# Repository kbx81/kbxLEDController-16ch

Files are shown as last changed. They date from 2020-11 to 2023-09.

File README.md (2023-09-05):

# kbx's 16-channel ESP32 Powered LED Strip Controller

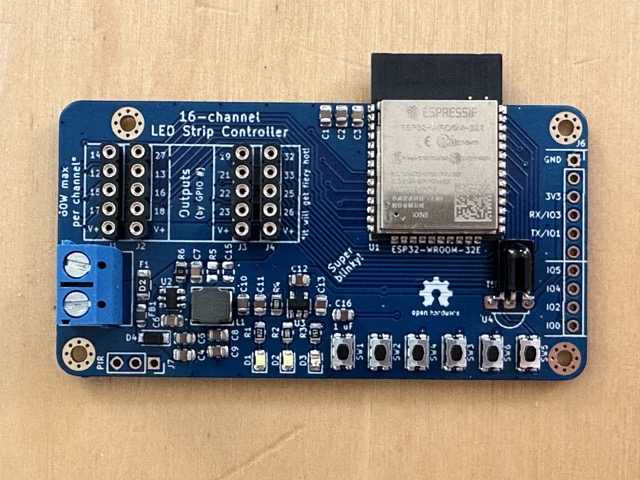
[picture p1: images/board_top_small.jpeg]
kbxLEDController-16ch PCB


## What?

Just another LED strip/tape controller...because the world needs more blinky! 💡

Note that this board is for linear/"analog" LED tape, not pixels/addressable LED tape. I recommend using a
[Quin LED](https://quinled.info) board if you need to power & drive pixels/addressable LED tape.

For more images, see the [gallery](GALLERY.md).

## Why?

I've been using more and more LED tape around my home. I wanted a replacement for/alternative to using multiple
[Magic Home](https://www.aliexpress.us/item/3256803342079819.html) LED controllers to operate multiple sections of LED
tape within a small area. Of course, having multiple controllers works, but, in my opinion, it's kind of silly and just
piles more unnecessary Wi-Fi devices onto my network. Soooooo why not make a single controller that can control a whole
bunch of strips from a single ESP32? Here we are.

In addition, I wanted something ESP32-based to minimize flicker; soft-PWM used on the ESP8266 drives me crazy in this
sense. A benefit of the ESP32 over the ESP8266 is that the ESP32 has _dedicated hardware_ for generating PWM. This
means that dimming of the LEDs is extremely smooth, consistent and flicker-free -- even at extremely low intensities!
While it's still possible on the ESP8266, LED control is just not as slick and really does not look as nice.

I've optimized this board for size (I wanted it small) and, to a lesser extent, cost. This is why it has machine-pin
headers instead of screw terminals for connecting the LED strips. I also designed it almost entirely with surface-mount
components to keep its overall footprint small -- you can easily hide it in/under a cabinet or behind/under a shelf.

While addressable LED tape is easier to drive, linear/"analog" LED tape tends to be significantly less expensive. As
fun as they are and as neat as they may look, I don't really need addressable LEDs everywhere -- linear strips work
just fine and look just as nice.

## How?

I use this board with [ESPHome](https://esphome.io) (and [Home Assistant](https://www.home-assistant.io)) but it should
work fine with [Tasmota](https://tasmota.github.io/docs/) or any other app, really.

I laid these boards out for [RGBW strips/tape](https://www.amazon.com/dp/B01D1I50UW), but they can be wired up to more
or less any kind of strips, whether monochrome, RGB, RGBW, RGBWW, the variable-color-temperature type...whatever.

They will work with a range of voltages, from 5 volts up to 24 volts.

Please see the BoM [here](kbxLEDController-16ch_bom.csv) or [here](https://octopart.com/bom-tool/OrMoA1no) for a list
of parts needed to build one. I had the PCBs fabricated by [Elecrow](https://www.elecrow.com) but nearly any PCB
fabricator should be able to manufacture these without any issues.

If you have PCBs fabricated, I _highly_ recommend having them made with 2 oz copper -- it costs a little more but
_significantly_ improves heat dissipation and allows for more current.

The schematic and PCB were drawn in [KiCad](https://www.kicad.org).

See the [ESPHome](ESPHome/) directory for a "demo" configuration you can use with [ESPHome](https://esphome.io) to test
the device after construction.

With the transistors in the BoM, _theoretically_ it should be good for up to about 60 watts per channel -- but watch
for excessive heat! Also...do not expect to be able to run all 16 channels at the full 60 watts. You're asking for
smoke and flames if you do so. Still, the layout should be pretty accommodating for high currents, especially if the
boards are fabricated with 2 oz copper (as they should be because current and heat).

## Legal stuff and License

The circuit schematics and PCB found here are licensed under the
[Creative Commons Attribution-ShareAlike 4.0 International License](http://creativecommons.org/licenses/by-sa/4.0/).



_Happy building!_

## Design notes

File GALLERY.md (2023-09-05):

# kbx's 16-channel ESP32 Powered LED Strip Controller Image Gallery

kbxLEDController-16ch PCB

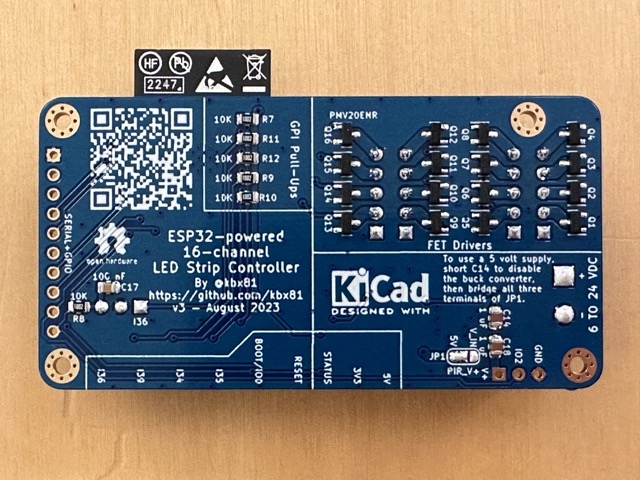
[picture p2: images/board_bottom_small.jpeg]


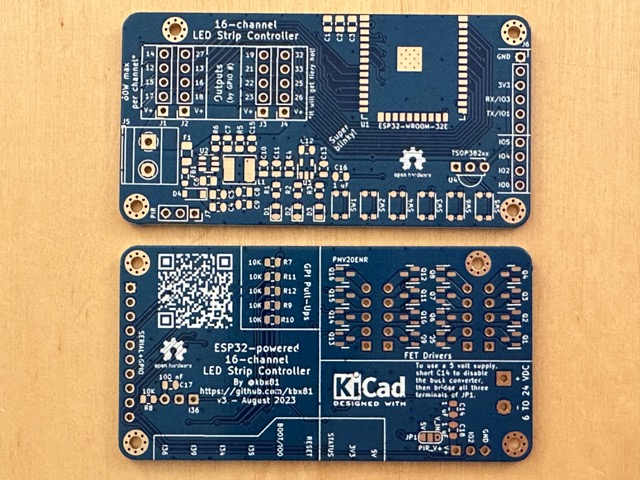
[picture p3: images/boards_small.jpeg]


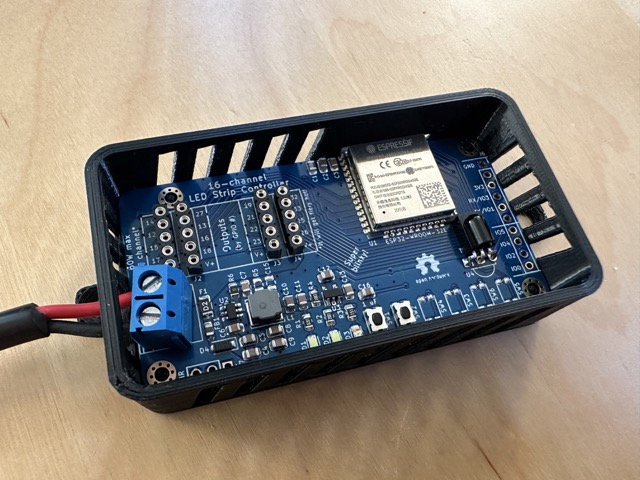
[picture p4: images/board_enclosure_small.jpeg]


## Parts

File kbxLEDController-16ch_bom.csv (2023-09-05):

Component | Quantity Per PCB | References | Value | MPN1 | Footprint | Population
1 | 4 | C3 C6 C7 C17 | 100 nF | CC0805KRX7R9BB104 | C_0805_2012Metric
2 | 7 | C2 C5 C11 C12 C14 C16 C18 | 1 uF | C2012X7R1H105K125AB | C_0805_2012Metric
3 | 3 | C1 C4 C13 | 10 uF | C2012X5R1V106K085AC | C_0805_2012Metric
4 | 3 | C8 C9 C10 | 22 uF | C2012X5R1V226M125AC | C_0805_2012Metric
5 | 2 | D1 D2 | White LED | LSM0805543V | LED_0805_2012Metric
6 | 1 | D4 | MBR120 | MBR120VLSFT1G | D_SOD-123
7 | 1 | D3 | Red LED | APT2012EC | LED_0805_2012Metric
8 | 1 | F1 | 250 mA | 1206L025/24YR | Fuse_1206_3216Metric
9 | 1 | FB1 | 600R/1A | 742792031 | L_0805_2012Metric
10 | 1 | L1 | 6.8 uH | LQH5BPN6R8M38L | L_Murata_LQH5BPN_4.9x4.9mm
11 | 16 | Q1 Q2 Q3 Q4 Q5 Q6 Q7 Q8 Q9 Q10 Q11 Q12 Q13 Q14 Q15 Q16 | PMV20ENR | PMV20ENR | SOT-23
12 | 1 | R6 | 0 | RC0805FR-070RL | R_0805_2012Metric
13 | 2 | R2 R3 | 2K | RC0805FR-072KL | R_0805_2012Metric
14 | 1 | R1 | 8K2 | RC0805FR-078K2L | R_0805_2012Metric
15 | 6 | R7 R8 R9 R10 R11 R12 | 10K | RC0805FR-0710KL | R_0805_2012Metric
16 | 1 | R4 | 100K | RC0805FR-07100KL | R_0805_2012Metric
17 | 6 | SW1 SW2 SW3 SW4 SW5 SW6 | Button | KMR221GLFS | SW_Push_1P1T_NO_CK_KMR2
18 | 1 | U3 | AP2112K-3.3 | AP2112K-3.3TRG1 | SOT-23-5
19 | 1 | U2 | AP63205WU | AP63205WU-7 | TSOT-23-6
20 | 1 | U1 | ESP32-WROOM-32E | ESP32-WROOM-32E | ESP32-WROOM-32
21 | 1 | U4 | TSOP382xx | TSOP38238 | Vishay_MINICAST-3Pin

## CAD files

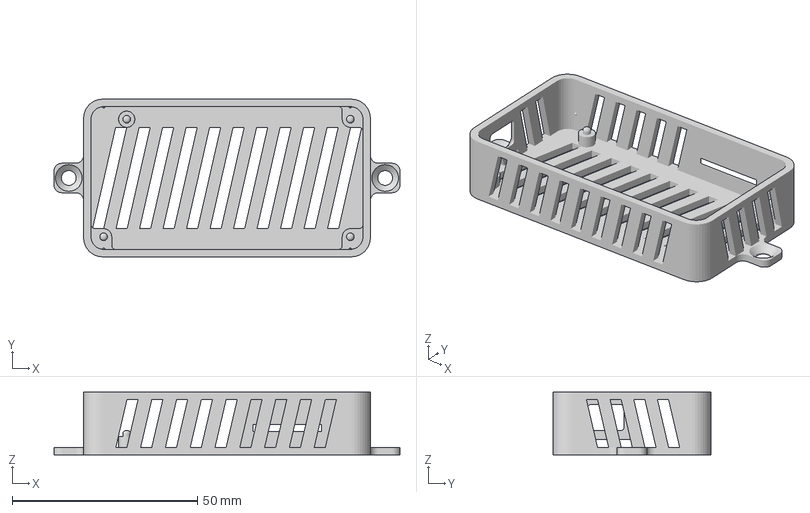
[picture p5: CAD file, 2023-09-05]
LEDController-Bottom-v3.3mf
93.5 x 42.6 x 17.0 mm

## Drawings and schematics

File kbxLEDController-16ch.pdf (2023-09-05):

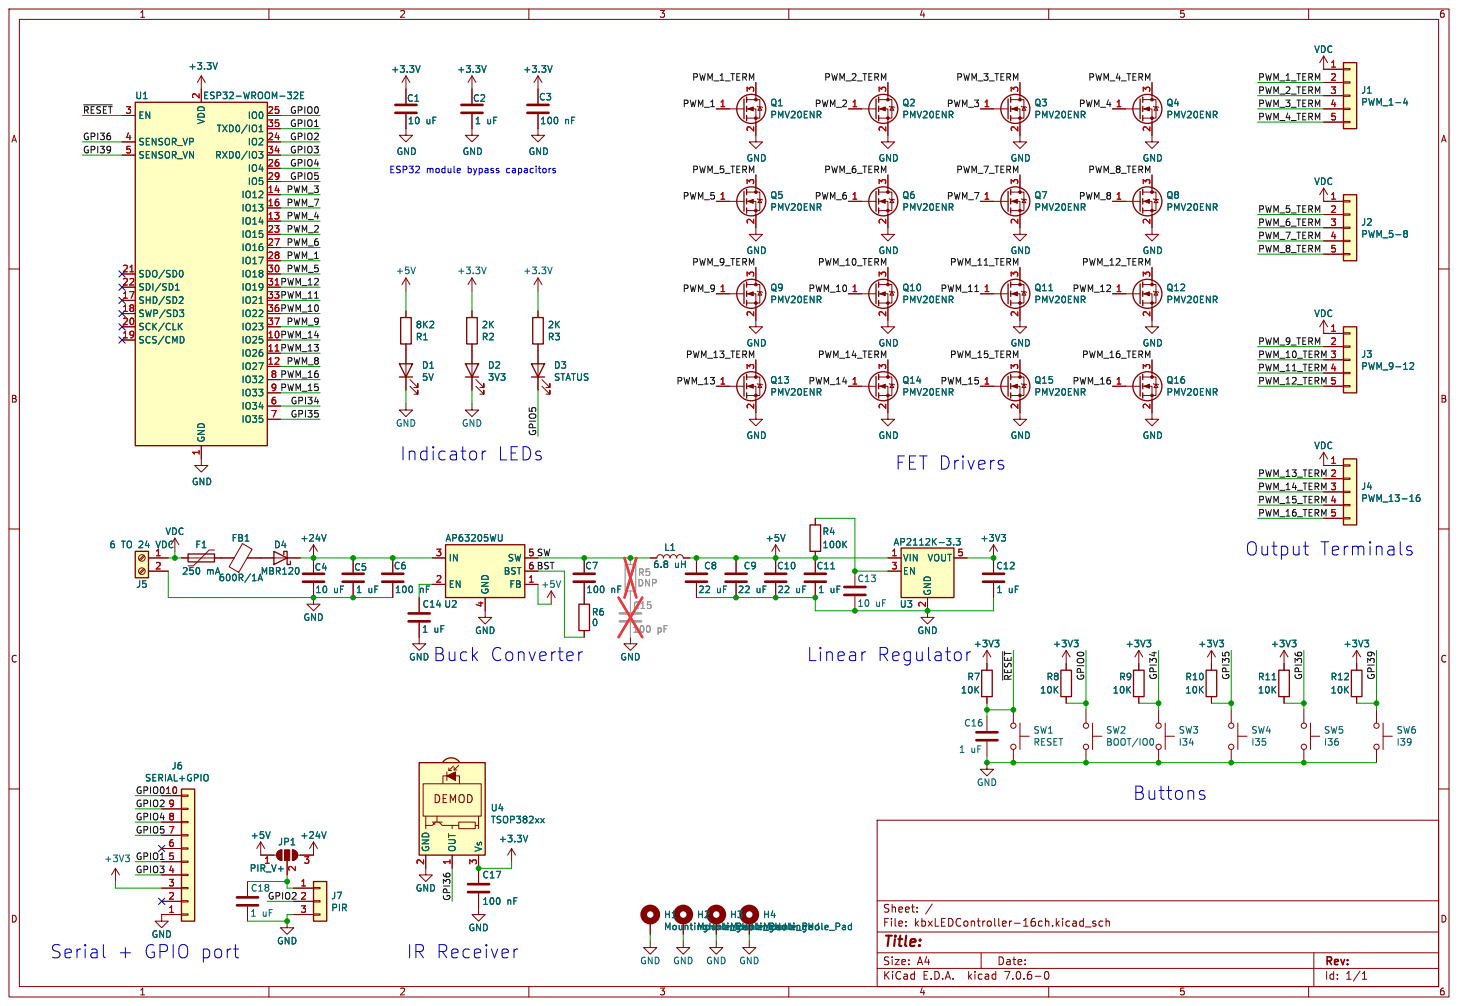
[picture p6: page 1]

2 SCK/CLK 20 SDO/SD0 21 SDI/SD1 22

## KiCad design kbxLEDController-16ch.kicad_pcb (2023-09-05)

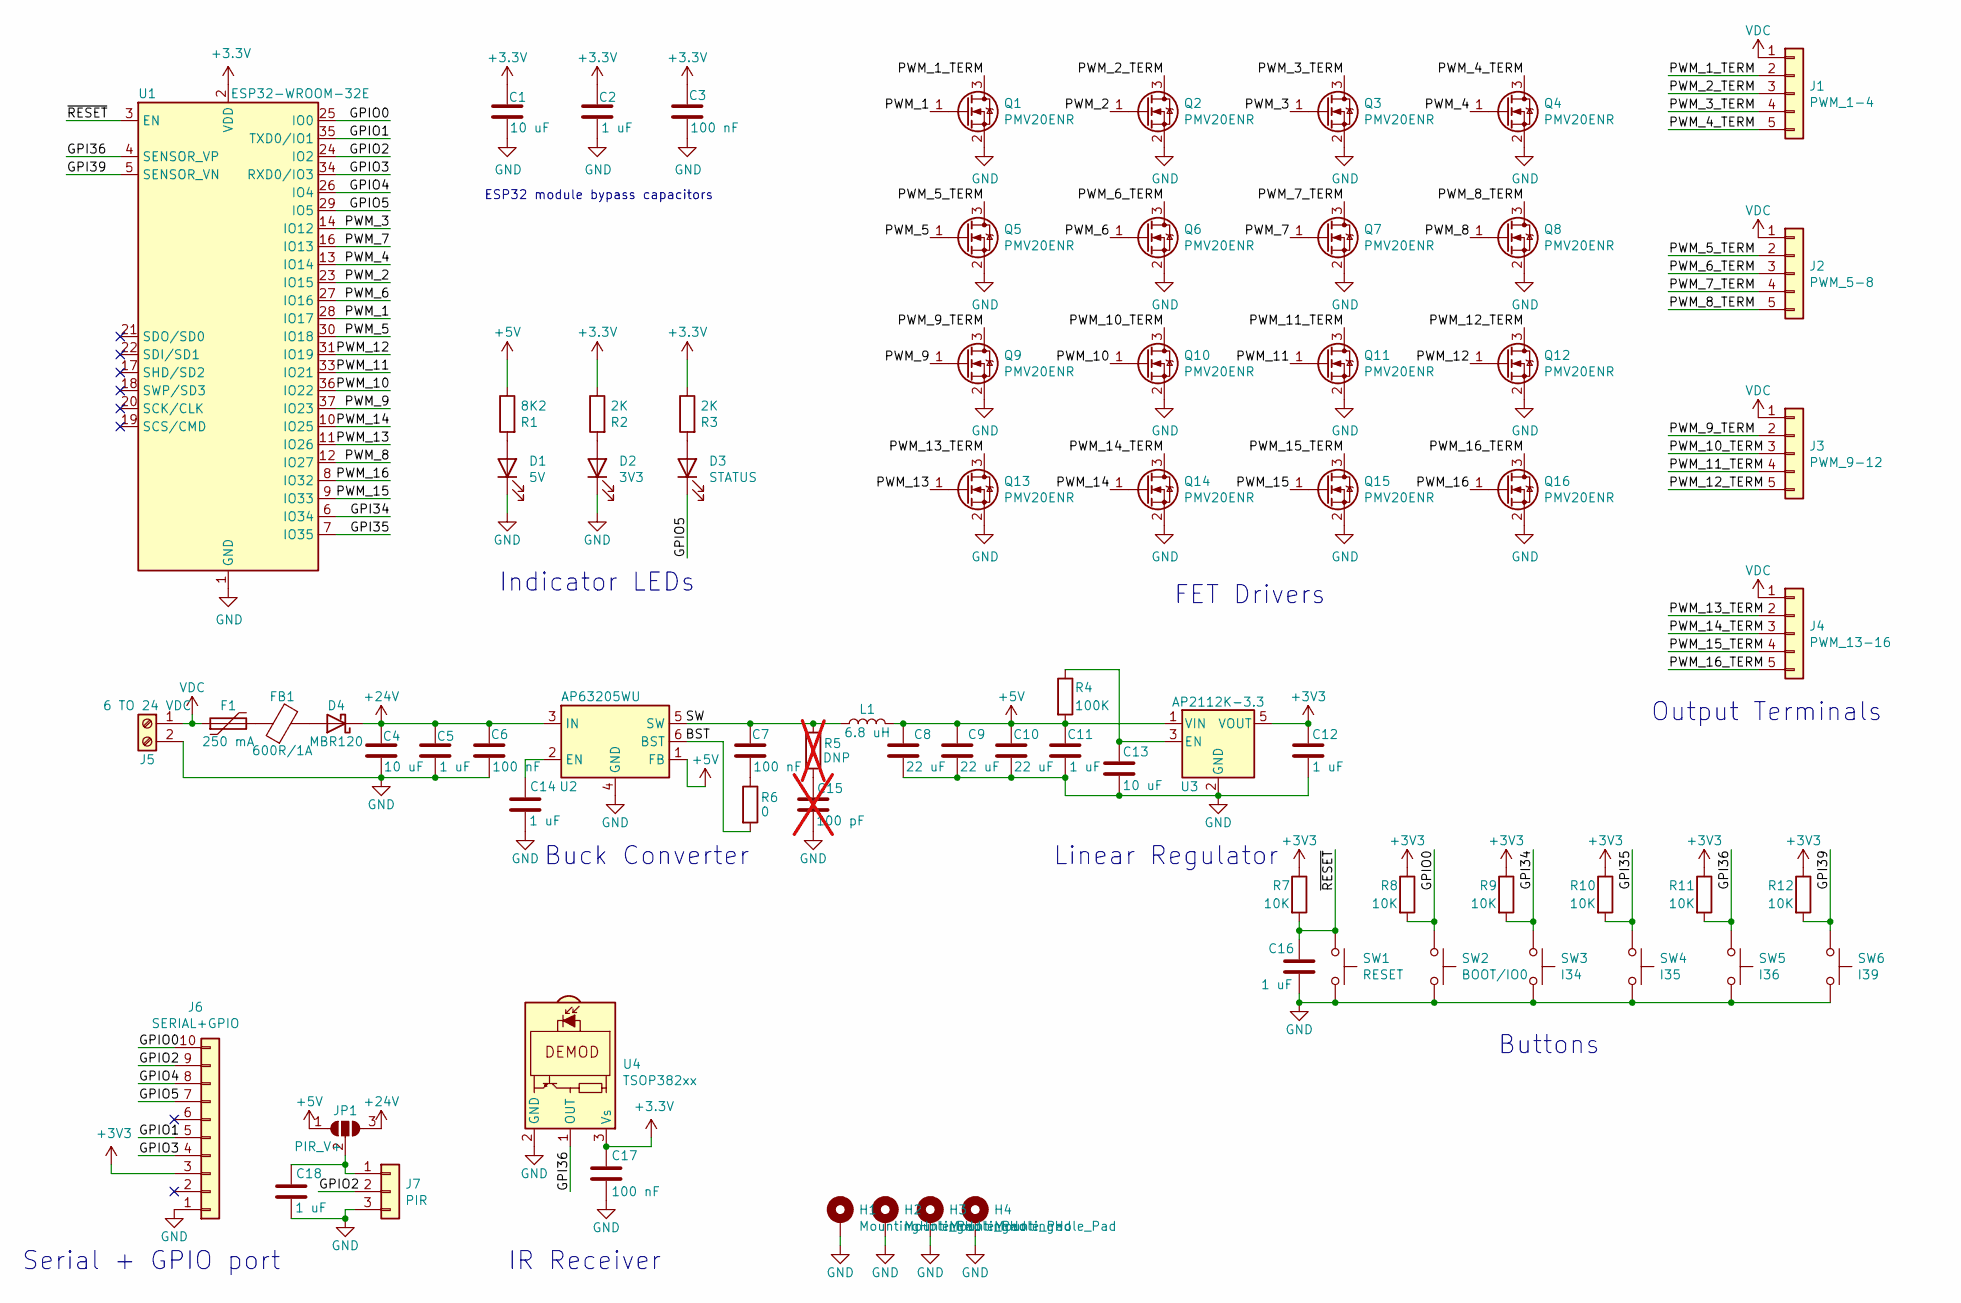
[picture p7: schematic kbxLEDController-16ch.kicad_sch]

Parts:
C1, C4, C13: 10 uF; C_0805_2012Metric; MPN1 C2012X5R1V106K085AC
C2, C5, C11, C12, C14, C16, C18: 1 uF; C_0805_2012Metric; MPN1 C2012X7R1H105K125AB
C3, C6, C7, C17: 100 nF; C_0805_2012Metric; MPN1 CC0805KRX7R9BB104
C8, C9, C10: 22 uF; C_0805_2012Metric; MPN1 C2012X5R1V226M125AC
C15: 100 pF; C_0805_2012Metric; MPN1 CC0805KRX7R9BB101; not fitted
D1: 5V; LED_0805_2012Metric; MPN1 LSM0805543V
D2: 3V3; LED_0805_2012Metric; MPN1 LSM0805543V
D3: STATUS; LED_0805_2012Metric; MPN1 APT2012EC
D4: MBR120; D_SOD-123; MPN1 MBR120VLSFT1G
F1: 250 mA; Fuse_1206_3216Metric; MPN1 1206L025/24YR
FB1: 600R/1A; L_0805_2012Metric; MPN1 742792031
H1, H2, H3, H4: MountingHole_Pad; MountingHole_2.2mm_M2_Pad_Via
J1: PWM_1-4; PinSocket_1x05_P2.54mm_Vertical
J2: PWM_5-8; PinSocket_1x05_P2.54mm_Vertical
J3: PWM_9-12; PinSocket_1x05_P2.54mm_Vertical
J4: PWM_13-16; PinSocket_1x05_P2.54mm_Vertical
J5: 6 TO 24 VDC; TerminalBlock_Phoenix_MKDS-1,5-2_1x02_P5.00mm_Horizontal; MPN1 1868733
J6: SERIAL+GPIO; PinSocket_1x10_P2.54mm_Vertical
J7: PIR; PinSocket_1x03_P2.54mm_Vertical
JP1: PIR_V+; SolderJumper-3_P1.3mm_Open_RoundedPad1.0x1.5mm_NumberLabels
L1: 6.8 uH; L_Murata_LQH5BPN_4.9x4.9mm; MPN1 LQH5BPN6R8M38L
Q1, Q2, Q3, Q4, Q5, Q6, Q7, Q8, Q9, Q10, Q11, Q12, Q13, Q14, Q15, Q16: PMV20ENR; SOT-23; MPN1 PMV20ENR
R1: 8K2; R_0805_2012Metric; MPN1 RC0805FR-078K2L
R2, R3: 2K; R_0805_2012Metric; MPN1 RC0805FR-072KL
R4: 100K; R_0805_2012Metric; MPN1 RC0805FR-07100KL
R5: DNP; R_0805_2012Metric; MPN1 RC0805FR-070RL; not fitted
R6: 0; R_0805_2012Metric; MPN1 RC0805FR-070RL
R7, R8, R9, R10, R11, R12: 10K; R_0805_2012Metric; MPN1 RC0805FR-0710KL
SW1: RESET; SW_Push_1P1T_NO_CK_KMR2; MPN1 KMR221GLFS
SW2: BOOT/IO0; SW_Push_1P1T_NO_CK_KMR2; MPN1 KMR221GLFS
SW3: I34; SW_Push_1P1T_NO_CK_KMR2; MPN1 KMR221GLFS
SW4: I35; SW_Push_1P1T_NO_CK_KMR2; MPN1 KMR221GLFS
SW5: I36; SW_Push_1P1T_NO_CK_KMR2; MPN1 KMR221GLFS
SW6: I39; SW_Push_1P1T_NO_CK_KMR2; MPN1 KMR221GLFS
U1: ESP32-WROOM-32E; ESP32-WROOM-32; MPN1 ESP32-WROOM-32E
U2: AP63205WU; TSOT-23-6; MPN1 AP63205WU-7
U3: AP2112K-3.3; SOT-23-5; MPN1 AP2112K-3.3TRG1
U4: TSOP382xx; Vishay_MINICAST-3Pin; MPN1 TSOP38238

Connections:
+5V: C8.2, C9.2, C10.2, C11.2, JP1.1 (A), L1.2, R1.1, R4.2, U2.1 (FB), U3.1 (VIN)
+24V: C4.2, C5.2, C6.2, D4.1 (K), JP1.3 (B), U2.3 (IN)
/BST: R6.2, U2.6 (BST)
/GPI34: R9.2, SW3.1, U1.6 (IO34)
/GPI35: R10.2, SW4.1, U1.7 (IO35)
/GPI36: R11.2, SW5.1, U1.4 (SENSOR_VP), U4.1 (OUT)
/GPI39: R12.2, SW6.1, U1.5 (SENSOR_VN)
/GPIO0: J6.10, R8.2, SW2.1, U1.25 (IO0)
/GPIO1: J6.5, U1.35 (TXD0/IO1)
/GPIO2: J6.9, J7.2, U1.24 (IO2)
/GPIO3: J6.4, U1.34 (RXD0/IO3)
/GPIO4: J6.8, U1.26 (IO4)
/GPIO5: D3.1 (K), J6.7, U1.29 (IO5)
/PWM_1: Q1.1 (G), U1.28 (IO17)
/PWM_1_TERM: J1.2, Q1.3 (D)
/PWM_2: Q2.1 (G), U1.23 (IO15)
/PWM_2_TERM: J1.3, Q2.3 (D)
/PWM_3: Q3.1 (G), U1.14 (IO12)
/PWM_3_TERM: J1.4, Q3.3 (D)
/PWM_4: Q4.1 (G), U1.13 (IO14)
/PWM_4_TERM: J1.5, Q4.3 (D)
/PWM_5: Q5.1 (G), U1.30 (IO18)
/PWM_5_TERM: J2.2, Q5.3 (D)
/PWM_6: Q6.1 (G), U1.27 (IO16)
/PWM_6_TERM: J2.3, Q6.3 (D)
/PWM_7: Q7.1 (G), U1.16 (IO13)
/PWM_7_TERM: J2.4, Q7.3 (D)
/PWM_8: Q8.1 (G), U1.12 (IO27)
/PWM_8_TERM: J2.5, Q8.3 (D)
/PWM_9: Q9.1 (G), U1.37 (IO23)
/PWM_9_TERM: J3.2, Q9.3 (D)
/PWM_10: Q10.1 (G), U1.36 (IO22)
/PWM_10_TERM: J3.3, Q10.3 (D)
/PWM_11: Q11.1 (G), U1.33 (IO21)
/PWM_11_TERM: J3.4, Q11.3 (D)
/PWM_12: Q12.1 (G), U1.31 (IO19)
/PWM_12_TERM: J3.5, Q12.3 (D)
/PWM_13: Q13.1 (G), U1.11 (IO26)
/PWM_13_TERM: J4.2, Q13.3 (D)
/PWM_14: Q14.1 (G), U1.10 (IO25)
/PWM_14_TERM: J4.3, Q14.3 (D)
/PWM_15: Q15.1 (G), U1.9 (IO33)
/PWM_15_TERM: J4.4, Q15.3 (D)
/PWM_16: Q16.1 (G), U1.8 (IO32)
/PWM_16_TERM: J4.5, Q16.3 (D)
/SW: C7.2, L1.1, R5.1, U2.5 (SW)
/~RESET: C16.1, R7.2, SW1.1, U1.3 (EN)
GND: C1.1, C2.1, C3.1, C4.1, C5.1, C6.1, C8.1, C9.1, C10.1, C11.1, C12.1, C13.1, C14.1, C15.1, C16.2, C17.2, C18.1, D1.1 (K), D2.1 (K), H1.1, H2.1, H3.1, H4.1, J5.2, J6.1, J7.3, Q1.2 (S), Q2.2 (S), Q3.2 (S), Q4.2 (S), Q5.2 (S), Q6.2 (S), Q7.2 (S), Q8.2 (S), Q9.2 (S), Q10.2 (S), Q11.2 (S), Q12.2 (S), Q13.2 (S), Q14.2 (S), Q15.2 (S), Q16.2 (S), SW1.2, SW2.2, SW3.2, SW4.2, SW5.2, SW6.2, U1.1 (GND), U1.15 (GND), U1.38 (GND), U1.39 (GND), U2.4 (GND), U3.2 (GND), U4.2 (GND)
unnamed: C7.1, R6.1
unnamed: C15.2, R5.2
unnamed: D1.2 (A), R1.2
unnamed: D2.2 (A), R2.2
unnamed: D3.2 (A), R3.2
unnamed: D4.2 (A), FB1.2
unnamed: F1.2, FB1.1
unnamed: C18.2, J7.1, JP1.2 (C)
unnamed: C14.2, U2.2 (EN)
unnamed: C13.2, R4.1, U3.3 (EN)
VDC: F1.1, J1.1, J2.1, J3.1, J4.1, J5.1

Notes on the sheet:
Linear Regulator
ESP32 module bypass capacitors
Buttons
FET Drivers
Serial + GPIO port
Output Terminals
Indicator LEDs
Buck Converter
IR Receiver

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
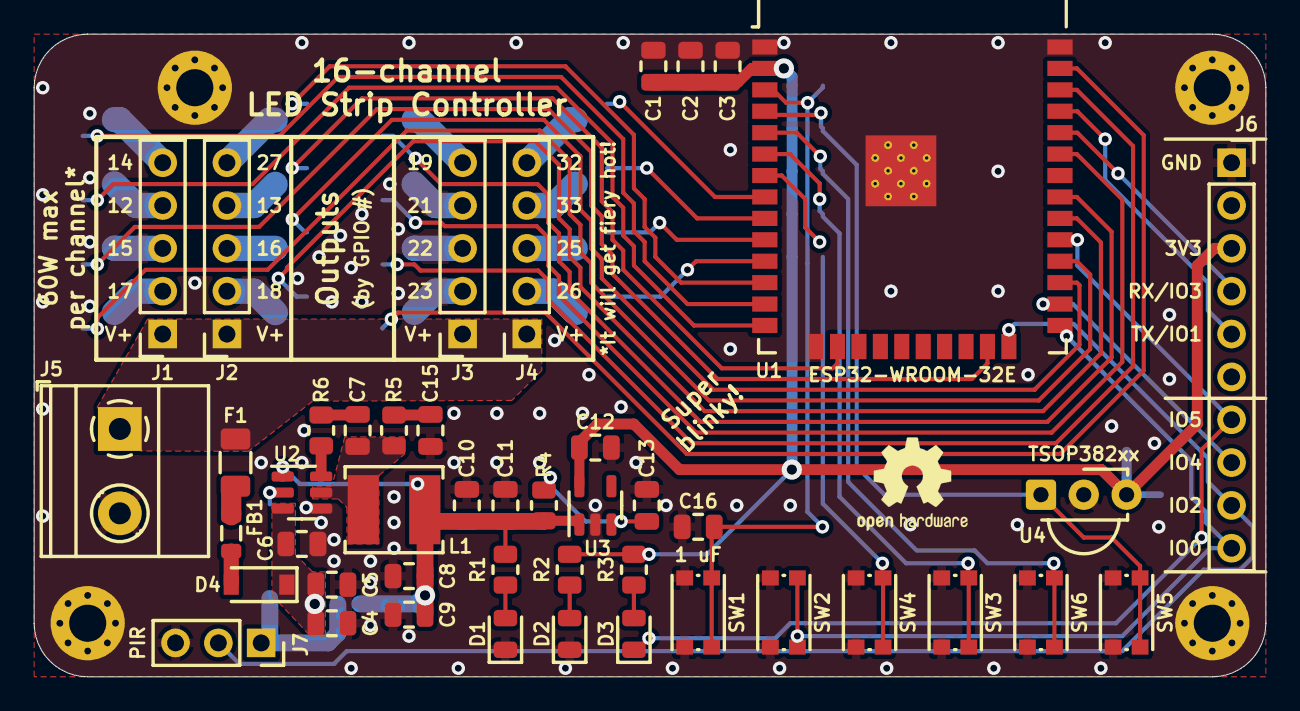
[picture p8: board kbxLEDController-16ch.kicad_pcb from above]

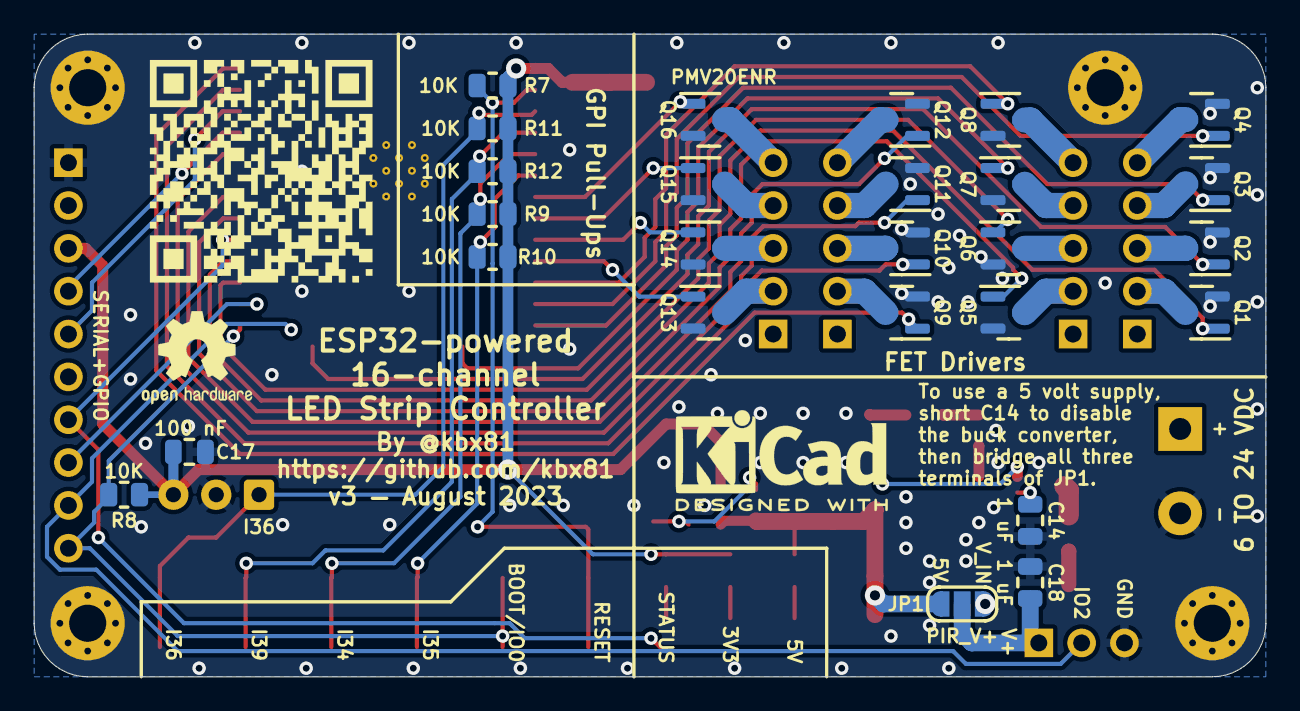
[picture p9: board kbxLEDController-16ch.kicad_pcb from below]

Board: 2 copper layers, 73.0 x 38.1 mm, 76 parts (27 on the bottom side), 60 nets.

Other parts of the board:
QR*****: QR

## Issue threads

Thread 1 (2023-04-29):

Stair light controller

jensenbox, 2023-04-29:
Thanks for making this available!

I was wondering if you could instruct me on a way to integrate 2 PIR sensors on to the board. I could probably manage it after a bunch of iterations but you seem like you would be way better at it than I would be.

I want to put 1 PIR sensor at the top of my stairs and the other at the bottom. When you go near one it starts a nice gradual cascade. There are other controllers on the market but none that I can control remotely. I want to be able to turn all the strips on whenever I want to for ambient lighting and when they are off they would react to a person walking.

I can do the software but I am very rusty on the hardware.

Any pointers?

kbx81, 2023-04-29:
If you want to specifically wire them into this board, there are already headers with extra some GPIOs exposed along the edges of the board.

Are you using ESPHome and Home Assistant? To minimize wiring, I'd just get a couple extra boards, perhaps D1 Minis or similar, connect your PIR sensors to those and use each to trigger an automation to switch on the lights you connect to this board. It means a couple of extra devices, but then you don't have to worry about running crazy lengths of wire to either end of your staircase.

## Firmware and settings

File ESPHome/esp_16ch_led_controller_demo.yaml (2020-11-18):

esphome:
  name: esp_16ch_led_controller_demo
  platform: ESP32
  board: featheresp32

wifi:
  ssid: "abcdefghijklmnop"
  password: "abcdefghijklmnop"

  # Enable fallback hotspot (captive portal) in case wifi connection fails
  ap:
    ssid: "esp_16ch_led_controller_demo"
    password: "abcdefghijklmnop"

captive_portal:

# Enable logging
logger:

# Enable Home Assistant API
api:
  password: "abcdefghijklmnop"

ota:
  password: "abcdefghijklmnop"

status_led:
  pin:
    number: GPIO5
    inverted: true

binary_sensor:
  - platform: gpio
    id: leds_off_button
    pin:
      number: GPIO0
      inverted: true
    on_click:
      min_length: 50ms
      max_length: 500ms
      then:
        - light.turn_off:
            id: j1_led_lights
        - light.turn_off:
            id: j2_led_lights
        - light.turn_off:
            id: j3_led_lights
        - light.turn_off:
            id: j4_led_lights
  - platform: gpio
    id: j1_led_on_button
    pin:
      number: GPIO35
      inverted: true
    on_click:
      min_length: 50ms
      max_length: 500ms
      then:
        - light.turn_on:
            id: j1_led_lights
            brightness: 0.5
            red: 1.0
            green: 1.0
            blue: 1.0
            white: 1.0
  - platform: gpio
    id: j2_led_on_button
    pin:
      number: GPIO34
      inverted: true
    on_click:
      min_length: 50ms
      max_length: 500ms
      then:
        - light.turn_on:
            id: j2_led_lights
            brightness: 0.5
            red: 1.0
            green: 1.0
            blue: 1.0
            white: 1.0
  - platform: gpio
    id: j3_led_on_button
    pin:
      number: GPIO39
      inverted: true
    on_click:
      min_length: 50ms
      max_length: 500ms
      then:
        - light.turn_on:
            id: j3_led_lights
            brightness: 0.5
            red: 1.0
            green: 1.0
            blue: 1.0
            white: 1.0
  - platform: gpio
    id: j4_led_on_button
    pin:
      number: GPIO36
      inverted: true
    on_click:
      min_length: 50ms
      max_length: 500ms
      then:
        - light.turn_on:
            id: j4_led_lights
            brightness: 0.5
            red: 1.0
            green: 1.0
            blue: 1.0
            white: 1.0

light:
  - platform: rgbw
    id: j1_led_lights
    name: "J1 Lights"
    red: j1_pwm_red_channel
    green: j1_pwm_green_channel
    blue: j1_pwm_blue_channel
    white: j1_pwm_white_channel
    effects:
      - random:
      - strobe:
      - flicker:
  - platform: rgbw
    id: j2_led_lights
    name: "J2 Lights"
    red: j2_pwm_red_channel
    green: j2_pwm_green_channel
    blue: j2_pwm_blue_channel
    white: j2_pwm_white_channel
    effects:
      - random:
      - strobe:
      - flicker:
  - platform: rgbw
    id: j3_led_lights
    name: "J3 Lights"
    red: j3_pwm_red_channel
    green: j3_pwm_green_channel
    blue: j3_pwm_blue_channel
    white: j3_pwm_white_channel
    effects:
      - random:
      - strobe:
      - flicker:
  - platform: rgbw
    id: j4_led_lights
    name: "J4 Lights"
    red: j4_pwm_red_channel
    green: j4_pwm_green_channel
    blue: j4_pwm_blue_channel
    white: j4_pwm_white_channel
    effects:
      - random:
      - strobe:
      - flicker:

output:
  - platform: ledc
    id: j1_pwm_red_channel
    pin: GPIO15
  - platform: ledc
    id: j1_pwm_green_channel
    pin: GPIO17
  - platform: ledc
    id: j1_pwm_blue_channel
    pin: GPIO12
  - platform: ledc
    id: j1_pwm_white_channel
    pin: GPIO14
  - platform: ledc
    id: j2_pwm_red_channel
    pin: GPIO16
  - platform: ledc
    id: j2_pwm_green_channel
    pin: GPIO18
  - platform: ledc
    id: j2_pwm_blue_channel
    pin: GPIO13
  - platform: ledc
    id: j2_pwm_white_channel
    pin: GPIO27
  - platform: ledc
    id: j3_pwm_red_channel
    pin: GPIO22
  - platform: ledc
    id: j3_pwm_green_channel
    pin: GPIO23
  - platform: ledc
    id: j3_pwm_blue_channel
    pin: GPIO21
  - platform: ledc
    id: j3_pwm_white_channel
    pin: GPIO19
  - platform: ledc
    id: j4_pwm_red_channel
    pin: GPIO25
  - platform: ledc
    id: j4_pwm_green_channel
    pin: GPIO26
  - platform: ledc
    id: j4_pwm_blue_channel
    pin: GPIO33
  - platform: ledc
    id: j4_pwm_white_channel
    pin: GPIO32
